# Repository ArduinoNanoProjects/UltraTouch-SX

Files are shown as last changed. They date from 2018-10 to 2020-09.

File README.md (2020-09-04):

 <pre>
 _   _  _  _                 _____                      _       _____ __   __
| | | || || |               |_   _|                    | |     /  ___|\ \ / /
| | | || || |_  _ __   __ _   | |    ___   _   _   ___ | |__   \ `--.  \ V /
| | | || || __|| '__| / _` |  | |   / _ \ | | | | / __|| '_ \   `--. \ /   \
| |_| || || |_ | |   | (_| |  | |  | (_) || |_| || (__ | | | | /\__/ // /^\ \
 \___/ |_| \__||_|    \__,_|  \_/   \___/  \__,_| \___||_| |_| \____/ \/   \/
 
Die Version der UltraTouch SX (Version 6) ist ausgestattet mit einem Nextion Display 
und sie versendet MIDI zur Nutzung der Räuspertasten. Sie kann vielseitig genutzt 
und erweitert werden ;)

Diese Idee entstand im Rahmen des Ultraschall-Projektes zum Themea: “MIDI Controller". 
Es gibt viele weitere Projekte von meinen Kollegen und der Podcast Community. 
Schau doch mal hier vorbei: https://ultraschall.fm

@developer   Michael McCouman Jr.
@version     UT[SX] V6
@date        04.Okt 2018 - 04.Seb 2020
@git:        https://github.com/McCouman
@website     https://wikibyte.org

Licence:     CC BY-NC-SA 4.0
Link:        https://creativecommons.org/licenses/by-nc-sa/4.0/deed.de
</pre>

# Overview

UltraTouch SX ist ein Midi-Controller für Podcaster. Sie kann als Räuspertaste aufgebaut und genutzt werden. Dies ist eine kleine Idee, wie ein Controller erarbeitet und gebaut werden kann:   

UltraTouch V6 - Overview

## Hard- und Software

### Arduino

Für dieses Projekt habe ich den <a href="https://store.arduino.cc/arduino-nano">Arduino Nano [0]</a> verwendet. Beachte, wenn Du größere Projekte aufbauen möchtest oder mehr Buttons benötigst, braucht dein Arduino mehr Speicher. Du benötigst daher, auf jedem Falle einen größeren Arduino für dein Projekt!

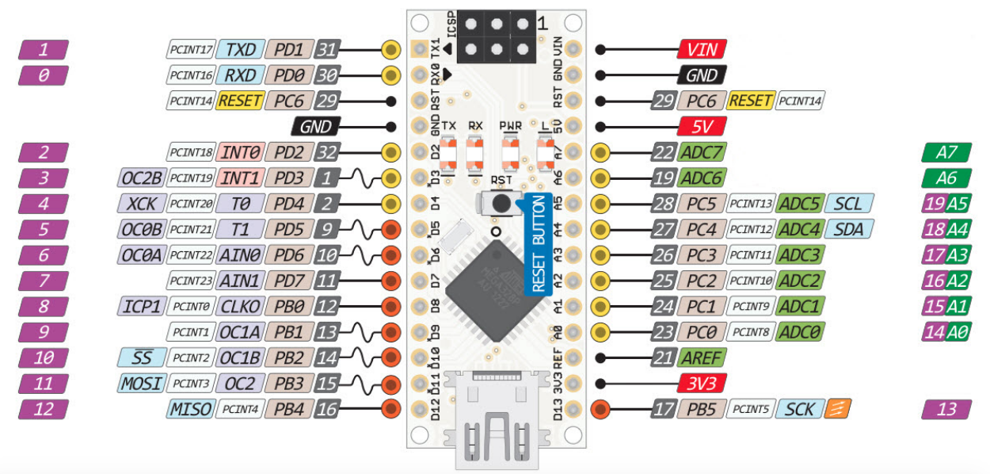
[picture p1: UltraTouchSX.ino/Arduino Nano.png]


### HC-SR04 Sensor

Das Ultraschall Modul HC-SR04 eignet sich zur Entfernungsmessung im Bereich zwischen 2cm und 2,5m mit einer Auflösung von 3mm. Es benötigt eine Versorgungsspannung von 5V bei einer Stromaufnahme von <2mA. Nach Triggerung misst das Modul
selbstständig die Entfernung und wandelt diese in ein PWM Signal welches am Ausgang zur Verfügung steht. Ein Messintervall hat dabei eine Dauer von 20ms. Es können daher 50 Messungen pro Sekunde durchgeführt werden. Es dient hier der schnellen und einfachen Lautstärkenanpassung über <i>Reaper Ultraschall</i>.

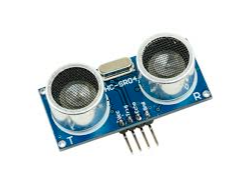
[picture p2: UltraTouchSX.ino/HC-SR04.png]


### WS-2812-B NeoPixel



Ein WS2812B wird auch kurz Neopixel genannt und es handelt sich hier um feste oder als Streifen vorhältige RGB LED. Ich habe für den beleuchteten Boden, 6 NeoPixel genutzt. Es können natürlich mehr oder weniger genutzt werden ;)

 

### Nextion Display

Das <a href="https://nextion.itead.cc">NextionDisplay [1]</a> ist eine einfache Möglichkeit sein eigenes Design und zusätzliche Software zu entwickeln. 

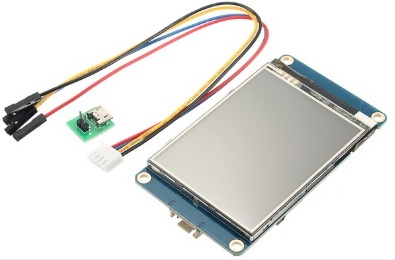
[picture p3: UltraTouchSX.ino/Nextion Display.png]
 

Die Software wird dabei direkt auf das Display geladen und kann über den Arduino angesprochen werden. Das in dieser Version genutzte Display ist das HMI TFT LCD Touch Display Module: <a href="https://www.itead.cc/nextion-nx4832t035.html">Nextion NX4832T035 - 3.5" [2]</a> (480 * 320). 

## Development

### LCARS Style (Design 2019)

Zur Entwicklung des Designs wurde <a href="https://www.adobe.com/de/products/photoshop.html">Photoshop <i>(R)(C)</i> [3]</a> benutzt. Das Design kann <a href="https://github.com/ArduinoNanoProjects/UltraTouch-SX/raw/master/NextionDisplay/UltraTouchSX-LCARS_2019/Data/PSD/UltraTouchSX-LCARS.psd">hier</a> geladen und verändert werden.

#### Load Screen
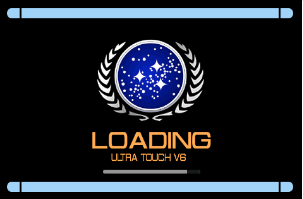
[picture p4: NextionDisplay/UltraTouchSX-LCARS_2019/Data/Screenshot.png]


##### Mute/Unmute Screen
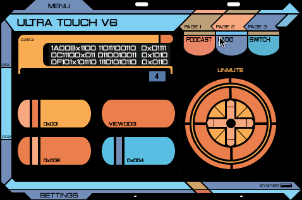
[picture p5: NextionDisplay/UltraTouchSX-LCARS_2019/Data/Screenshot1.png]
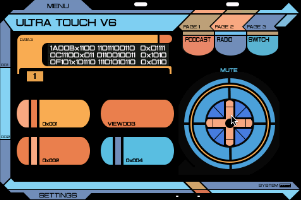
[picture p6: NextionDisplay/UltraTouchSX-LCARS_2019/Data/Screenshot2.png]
 

##### Settings Screen
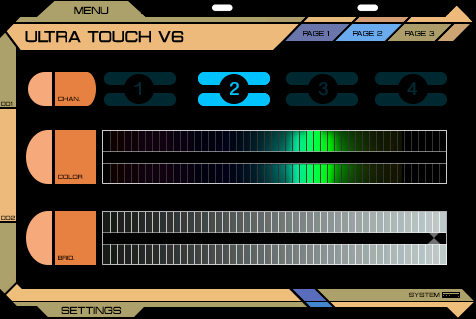
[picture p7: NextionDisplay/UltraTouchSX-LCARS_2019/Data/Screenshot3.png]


### U4 Style (Design 2020)

Zur Entwicklung des Designs wurde <a href="https://www.adobe.com/de/products/photoshop.html">Photoshop <i>(R)(C)</i> [3]</a> benutzt. Das Design 2020 kann <a href="https://github.com/ArduinoNanoProjects/UltraTouch-SX/raw/master/NextionDisplay/UltraTouchSX-U4_2020/Design-UltraTouch%20SX6%20US4/PSD/UltraTouchSX-U4.psd">hier</a> geladen und verändert werden.

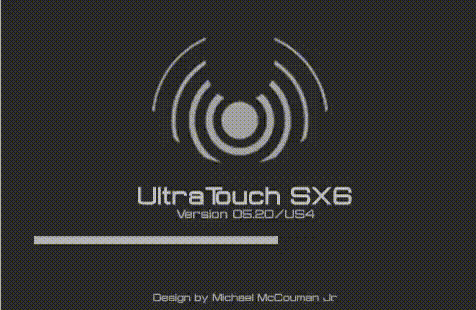
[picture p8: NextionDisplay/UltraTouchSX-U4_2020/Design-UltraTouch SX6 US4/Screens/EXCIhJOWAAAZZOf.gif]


https://twitter.com/i/status/1256654848210198529

Lade das "Betriebssystem" (<a href="https://github.com/ArduinoNanoProjects/UltraTouch-SX/raw/master/NextionDisplay/UltraTouchSX-U4_2020/UltraTouchSX6-US4.HMI">HMI</a>) auf das Nextion Display. Bearbeiten kannst Du es über das <a href="https://github.com/ArduinoNanoProjects/UltraTouch-SX/raw/master/NextionDisplay/UltraTouchSX-U4_2020/Design-UltraTouch%20SX6%20US4/UltraTouchSX6-US4.tft">UltraTouchSX6-US4.tft</a>.

#### Load Screen
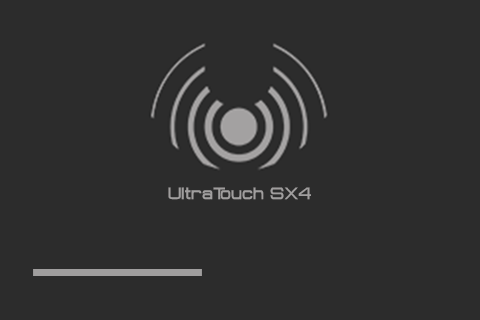
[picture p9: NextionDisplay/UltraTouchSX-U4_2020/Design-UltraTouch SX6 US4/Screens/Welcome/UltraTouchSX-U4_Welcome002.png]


##### Mute/Unmute Screen
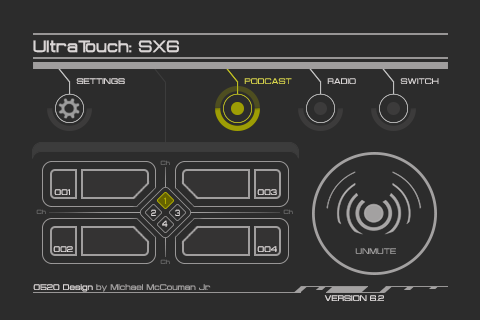
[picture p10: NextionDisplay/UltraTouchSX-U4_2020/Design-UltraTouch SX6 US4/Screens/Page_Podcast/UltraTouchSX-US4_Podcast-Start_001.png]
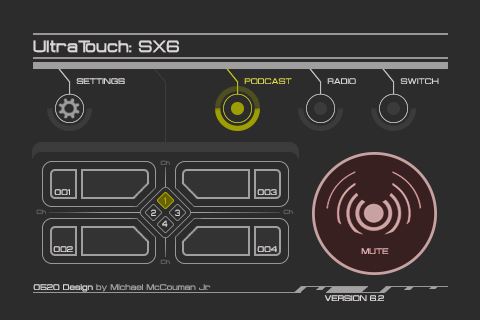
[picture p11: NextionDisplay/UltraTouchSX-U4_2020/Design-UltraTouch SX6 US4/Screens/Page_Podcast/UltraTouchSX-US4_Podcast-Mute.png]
 

##### Settings Screen
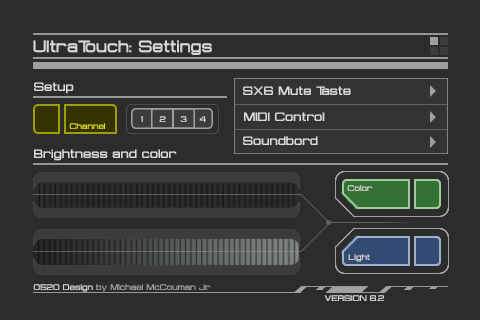
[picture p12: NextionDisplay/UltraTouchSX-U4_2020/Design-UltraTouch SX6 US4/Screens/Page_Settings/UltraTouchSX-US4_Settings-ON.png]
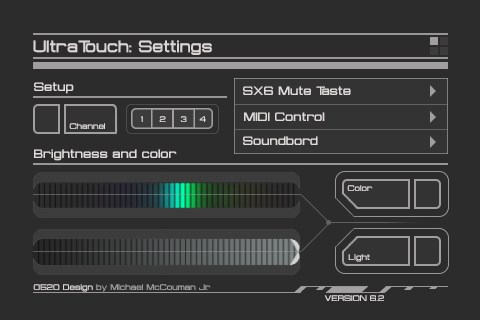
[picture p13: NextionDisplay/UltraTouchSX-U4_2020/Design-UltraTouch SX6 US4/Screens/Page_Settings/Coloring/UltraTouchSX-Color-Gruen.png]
 

#### 3D-Modell

<a href="https://github.com/ArduinoNanoProjects/UltraTouch-SX/tree/master/3D-Model">Hier</a> findest Du die 3d Modelle für das Gehäuse der UltraTouch SX für deinen 3D Printer. Ich habe hier den Desktop 3D-Drucker (Ender 2) genutzt, um das Gehäuse zu drucken. Der Druck besteht aus fünf einzelnen Modellen, die ich jedoch mit unterschiedlichen Materialien gedruckt habe:

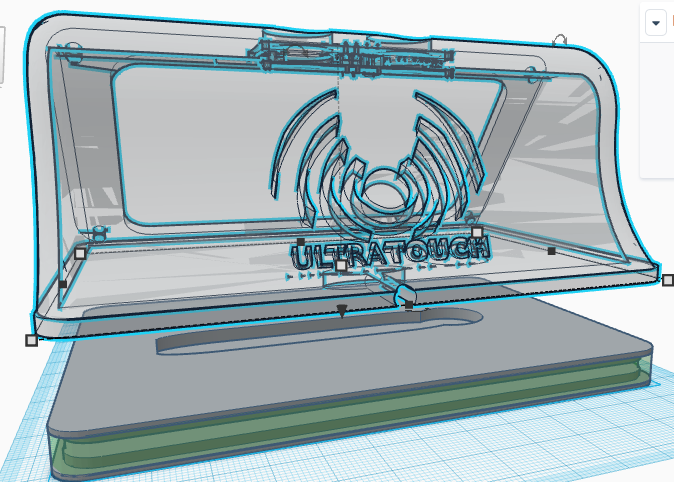
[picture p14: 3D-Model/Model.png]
UltraTouch Model für 3D Printer


- Body: ist das Gehäuse (schwarz: PLA)
- top_box: ist der Verbund für das Display (silber: PLA)
- Top: ist der obere Bereich der LED Box (silber: PETG)
- Bottom: ist der untere Bereich der LED Box (silber: PETG)
- Transparent: ist der Transparente Bereich der LED Box (transparent, dark glow: PLA)

*Achtung: Je nach Material gibt es unterschiedliche fließverhalten der Kunststoffe. Sie haben daher unterschiedlichen Schwund beim Drucken. Möchte man ein z.B. rein PLA-Material nutzen, so muss das Design angepasst werden oder nachträglich bearbeitet werden.*

### GUI Development

Des weiteren wird die IDE: Nextion Editor benötigt, um den Kernel der GUI als laufendes Systems zu entwickeln. Die Software ist leider nur für Windows erhältlich und kann direkt auf der Website von <a href="https://nextion.itead.cc/resources/download/">Nextion [4]</a> heruntergeladen werden. 

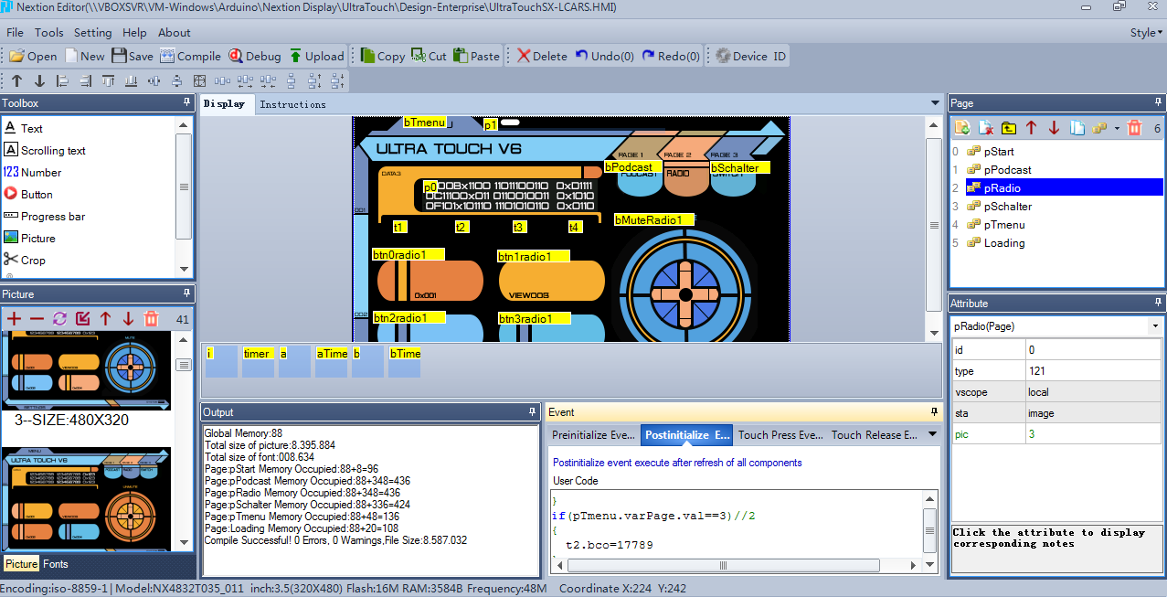
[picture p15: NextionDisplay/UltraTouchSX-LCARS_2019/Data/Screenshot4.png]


Zum laden des Projektes muss das "Betriebssystem", die <a href="https://github.com/ArduinoNanoProjects/UltraTouch-SX/raw/master/NextionDisplay/UltraTouchSX-LCARS_2019/UltraTouchSX-LCARS.HMI">UltraTouchSX-LCARS.HMI</a> oder <a href="https://github.com/ArduinoNanoProjects/UltraTouch-SX/raw/master/NextionDisplay/UltraTouchSX-U4_2020/UltraTouchSX6-US4.HMI">UltraTouchSX6-US4.HMI</a> mit dem <i>Nextion Exitor</i> geladen werden. Dabei wird des Betreibersystem auf das Display überspielt/geflashed.

### API Development

Hier findet sich der <a href="https://github.com/ArduinoNanoProjects/UltraTouch-SX/blob/master/UltraTouchSX.ino/UltraTouchSX/UltraTouchSX.ino">Beispiel Code</a> meiner UltraTouch SX in der Version 6.0 Variante. 

## Externe Links
- [0] Arduino Nano: https://store.arduino.cc/arduino-nano
- [1] Nextion Website: https://nextion.itead.cc
- [2] Nextion Display 3,5": https://www.itead.cc/nextion-nx4832t035.html
- [3] Photoshop: https://www.adobe.com/de/products/photoshop.html
- [4] Nextion Editor: https://nextion.itead.cc/resources/download/

## Lizenz
Diese Software steht unter CC BY-NC-SA 4.0 - Lizenz: Namensnennung - Nicht-kommerziell - Weitergabe unter gleichen Bedingungen 4.0 International (CC BY-NC-SA 4.0)

Dies ist eine allgemeinverständliche Zusammenfassung der Lizenz (die diese nicht ersetzt). Haftungsbeschränkung.

**Sie dürfen:**

* Teilen — das Material in jedwedem Format oder Medium vervielfältigen und weiterverbreiten
* Bearbeiten — das Material remixen, verändern und darauf aufbauen

Der Lizenzgeber kann diese Freiheiten nicht widerrufen solange Sie sich an die Lizenzbedingungen halten.

**Unter folgenden Bedingungen:**

* Namensnennung — Sie müssen angemessene Urheber- und Rechteangaben machen, einen Link zur Lizenz beifügen und angeben, ob Änderungen vorgenommen wurden. Diese Angaben dürfen in jeder angemessenen Art und Weise gemacht werden, allerdings nicht so, dass der Eindruck entsteht, der Lizenzgeber unterstütze gerade Sie oder Ihre Nutzung besonders.

* Nicht kommerziell — Sie dürfen das Material nicht für kommerzielle Zwecke nutzen.

* Weitergabe unter gleichen Bedingungen — Wenn Sie das Material remixen, verändern oder anderweitig direkt darauf aufbauen, dürfen Sie Ihre Beiträge nur unter derselben Lizenz wie das Original verbreiten.

* Keine weiteren Einschränkungen — Sie dürfen keine zusätzlichen Klauseln oder technische Verfahren einsetzen, die anderen rechtlich irgendetwas untersagen, was die Lizenz erlaubt.

**Hinweise:**

Sie müssen sich nicht an diese Lizenz halten hinsichtlich solcher Teile des Materials, die gemeinfrei sind, oder soweit Ihre Nutzungshandlungen durch Ausnahmen und Schranken des Urheberrechts gedeckt sind.

Es werden keine Garantien gegeben und auch keine Gewähr geleistet. Die Lizenz verschafft Ihnen möglicherweise nicht alle Erlaubnisse, die Sie für die jeweilige Nutzung brauchen. Es können beispielsweise andere Rechte wie Persönlichkeits- und Datenschutzrechte zu beachten sein, die Ihre Nutzung des Materials entsprechend beschränken.

Link: https://creativecommons.org/licenses/by-nc-sa/4.0/deed.de

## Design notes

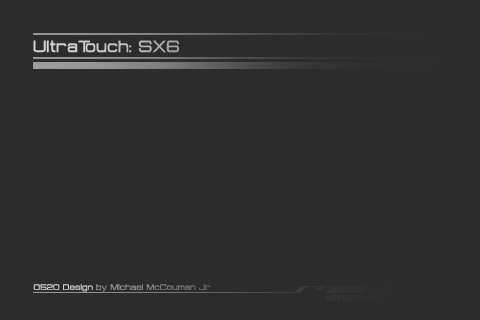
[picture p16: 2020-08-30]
NextionDisplay/UltraTouchSX-U4_2020/Design-UltraTouch SX6 US4/Screens/Loading-GIF_Home/UltraTouchSX-US4_LodingHome-002.png

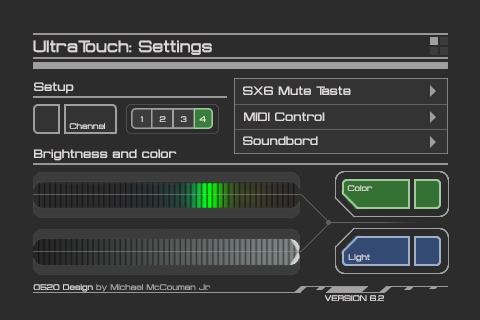
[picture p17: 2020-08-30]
NextionDisplay/UltraTouchSX-U4_2020/Design-UltraTouch SX6 US4/Screens/Page_Settings/Channel/UltraTouchSX-Channel4.png

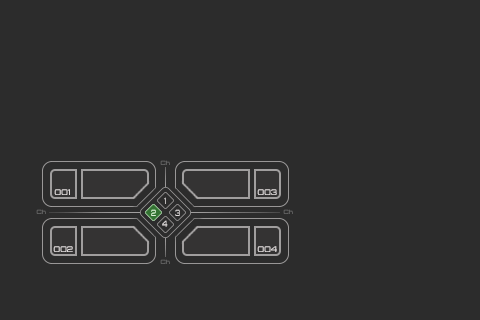
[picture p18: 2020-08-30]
NextionDisplay/UltraTouchSX-U4_2020/Design-UltraTouch SX6 US4/Screens/Views_Channel/UltraTouchSX-US4_Ch_2.png

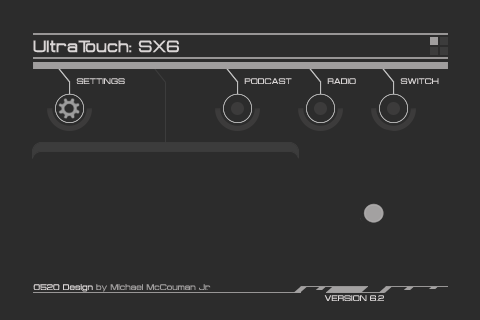
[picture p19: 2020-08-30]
NextionDisplay/UltraTouchSX-U4_2020/Design-UltraTouch SX6 US4/Screens/Loading-GIF_Home/UltraTouchSX-US4_LodingHome-009.png

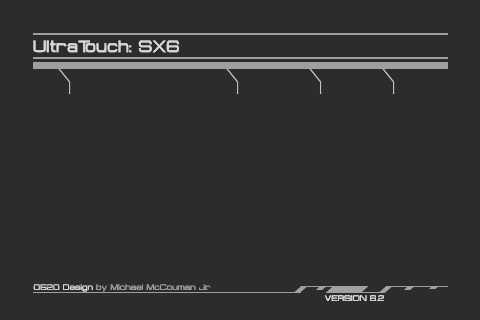
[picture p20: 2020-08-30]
NextionDisplay/UltraTouchSX-U4_2020/Design-UltraTouch SX6 US4/Screens/Loading-GIF_Home/UltraTouchSX-US4_LodingHome-005.png

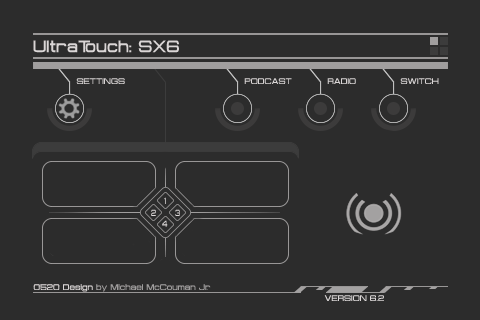
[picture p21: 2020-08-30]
NextionDisplay/UltraTouchSX-U4_2020/Design-UltraTouch SX6 US4/Screens/Loading-GIF_Home/UltraTouchSX-US4_LodingHome-011.png

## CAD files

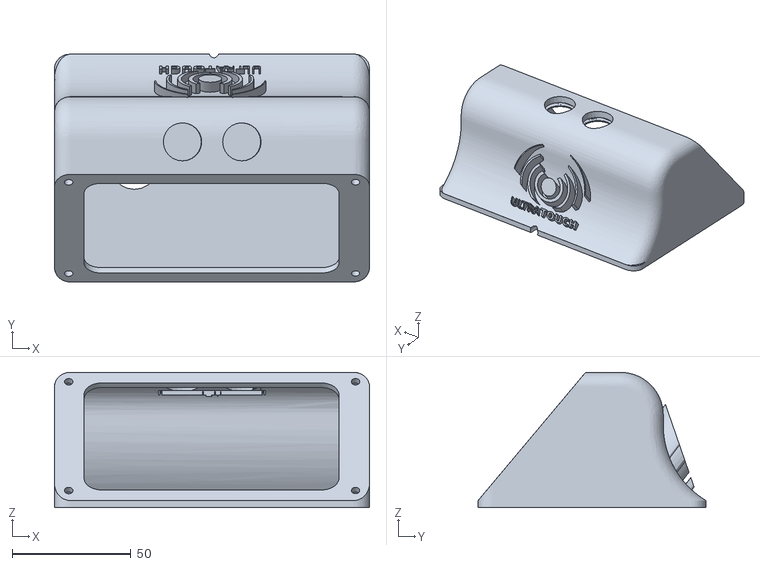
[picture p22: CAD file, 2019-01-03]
3D-Model/Body.stl
132.6 x 96.0 x 57.0

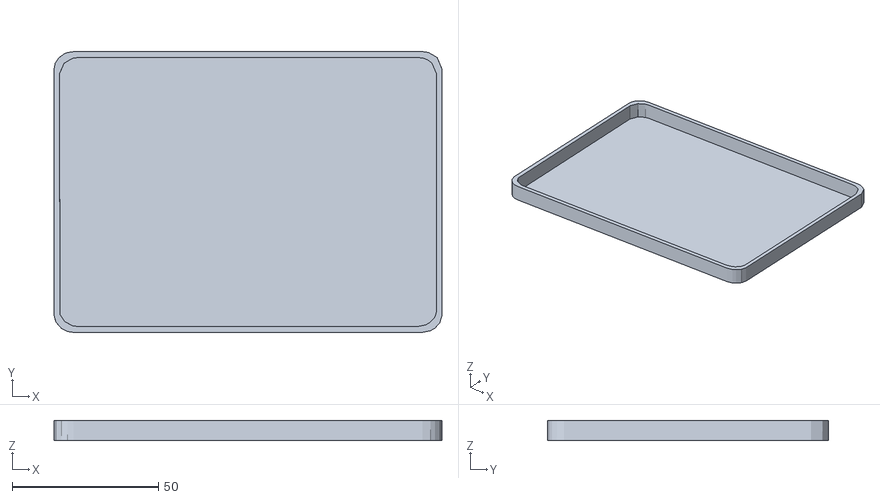
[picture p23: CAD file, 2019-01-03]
3D-Model/Transparent.stl
132.6 x 96.0 x 7.00

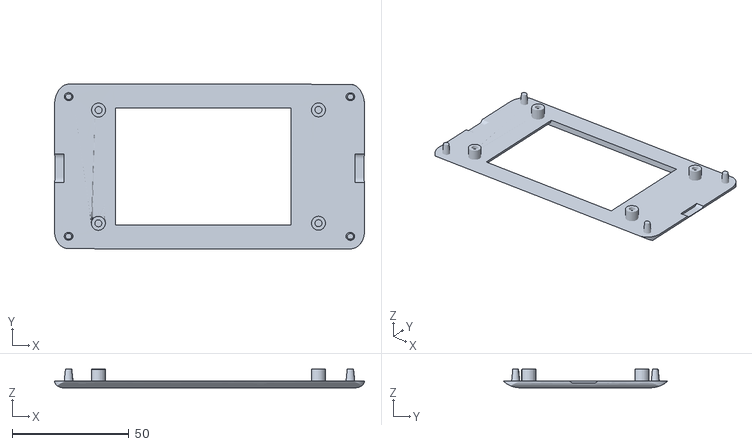
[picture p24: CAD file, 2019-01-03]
3D-Model/top_box.stl
132.7 x 70.5 x 8.02

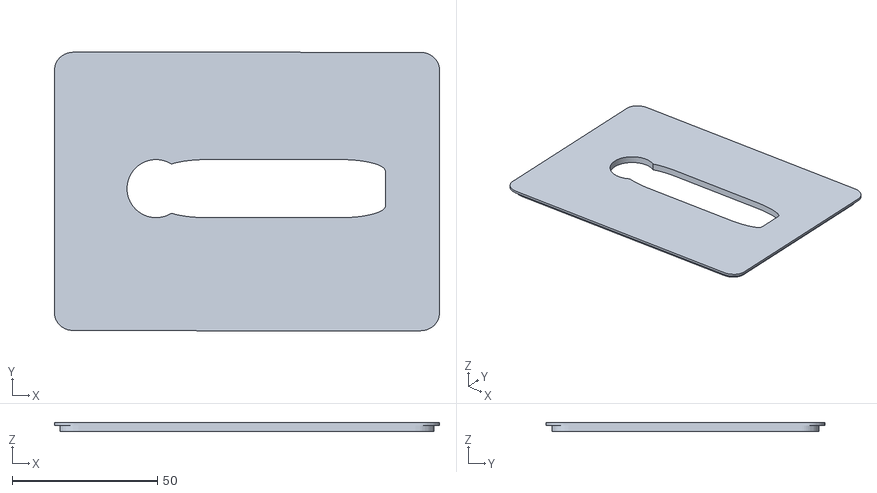
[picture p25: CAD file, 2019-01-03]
3D-Model/Top.stl
132.6 x 96.0 x 3.00

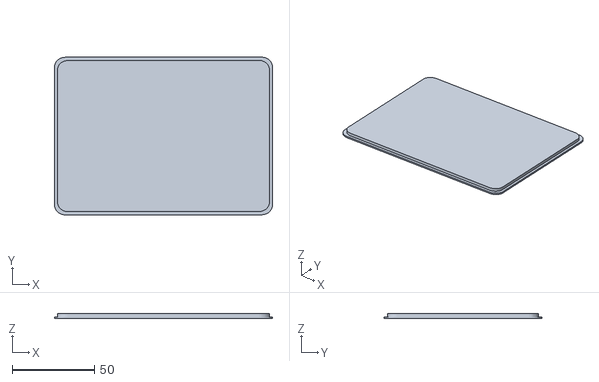
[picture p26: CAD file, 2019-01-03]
3D-Model/Bottom.stl
132.6 x 96.0 x 2.99

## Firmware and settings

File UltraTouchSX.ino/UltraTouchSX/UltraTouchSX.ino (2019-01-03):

/**
 *   _   _  _  _                 _____                      _       _____ __   __
 *  | | | || || |               |_   _|                    | |     /  ___|\ \ / /
 *  | | | || || |_  _ __   __ _   | |    ___   _   _   ___ | |__   \ `--.  \ V / 
 *  | | | || || __|| '__| / _` |  | |   / _ \ | | | | / __|| '_ \   `--. \ /   \ 
 *  | |_| || || |_ | |   | (_| |  | |  | (_) || |_| || (__ | | | | /\__/ // /^\ \
 *   \___/ |_| \__||_|    \__,_|  \_/   \___/  \__,_| \___||_| |_| \____/ \/   \/                                                                          
 *   
 * 
 * Die Version der UltraTouch SX (Version 6) ist ausgestattet mit einem Nextion-Display (R) 
 * und sie versendet MIDI zur Nutzung der Räuspertasten. Sie kann vielseitig genutzt, verändert 
 * und eingesetzt werden ;)
 * 
 * Diese Idee entstand im Rahmen des Ultraschall-Projektes zum Themea: "MIDI Controller". Es gibt 
 * viele weitere Projekte von mir und meinen Kollegen. 
 * Schaue doch mal vorbei: https://ultraschall.fm.
 * 
 * 
 * @developer   Michael McCouman Jr.
 * @version     UT[SX] V6
 * @date        04.Okt 2018 - 03. Jan 2019
 * @git:        https://github.com/McCouman
 * @website     https://wikibyte.org
 * 
 * Licence:     CC BY-NC-SA 4.0
 * Link:        https://creativecommons.org/licenses/by-nc-sa/4.0/deed.de
 *
**/

/*
 
   INFORMATIONEN ZUR LIZENZ:
   
   Diese Software steht unter CC BY-NC-SA 4.0 Lizenz: Namensnennung - Nicht-kommerziell - Weitergabe unter gleichen Bedingungen 
   4.0 International (CC BY-NC-SA 4.0). Dies ist eine allgemeinverständliche Zusammenfassung der Lizenz (die diese nicht ersetzt). 
   
   HAFTUNGSBESCHRÄNKUNG:
   
   Sie dürfen:
   - Teilen — das Material in jedwedem Format oder Medium vervielfältigen und weiterverbreiten
   - Bearbeiten — das Material remixen, verändern und darauf aufbauen
   - Der Lizenzgeber kann diese Freiheiten nicht widerrufen solange Sie sich an die Lizenzbedingungen halten.
   
   Unter folgenden Bedingungen:
   - Namensnennung — Sie müssen angemessene Urheber- und Rechteangaben machen, einen Link zur Lizenz beifügen und angeben, 
     ob Änderungen vorgenommen wurden. Diese Angaben dürfen in jeder angemessenen Art und Weise gemacht werden, allerdings 
     nicht so, dass der Eindruck entsteht, der Lizenzgeber unterstütze gerade Sie oder Ihre Nutzung besonders.
   
   - Nicht kommerziell — Sie dürfen das Material nicht für kommerzielle Zwecke nutzen.
   
   - Weitergabe unter gleichen Bedingungen — Wenn Sie das Material remixen, verändern oder anderweitig direkt darauf aufbauen, 
     dürfen Sie Ihre Beiträge nur unter derselben Lizenz wie das Original verbreiten.
   
   - Keine weiteren Einschränkungen — Sie dürfen keine zusätzlichen Klauseln oder technische Verfahren einsetzen, 
     die anderen rechtlich irgendetwas untersagen, was die Lizenz erlaubt.
   
   
   Hinweise:
   Sie müssen sich nicht an diese Lizenz halten hinsichtlich solcher Teile des Materials, die gemeinfrei sind, 
   oder soweit Ihre Nutzungshandlungen durch Ausnahmen und Schranken des Urheberrechts gedeckt sind. Es werden keine Garantien 
   gegeben und auch keine Gewähr geleistet. Die Lizenz verschafft Ihnen möglicherweise nicht alle Erlaubnisse, die Sie für die 
   jeweilige Nutzung brauchen. Es können beispielsweise andere Rechte wie Persönlichkeits- und Datenschutzrechte zu beachten sein, 
   die Ihre Nutzung des Materials entsprechend beschränken.
   
   Link:
   - https://creativecommons.org/licenses/by-nc-sa/4.0/deed.de

 * 
*/

// BIBLIOTHEK:
#include "Nextion.h"

#include <Adafruit_NeoPixel.h>
#ifdef __AVR__
  #include <avr/power.h>
#endif

// LED PIN:
#define LED         13   // OnBoard LED des Arduino Nanos
#define PIN         12   // Signal Pin für NeoPixel
#define NUMPIXELS    6   // Anzahl der NeoPixel

// VARS:
int Toggle      = HIGH;  // Speichert den Wert des Button Peak View
int Switch      = HIGH;  // Speichert den Wert des MIDI-Schalters 
int Bridhness   = 255;   // Speichert den Wert der Helligkeit für die Bodenbeleuchtung
int Modus       = 1;     // Speichert den Wert ob Mute oder Unmute für die Farben eines Callbacks
int Channel     = 1;     // Speichert die Werte für die Kanäle 1 bis 4 für die Mute/Unmute Taste
int Colors      = 1;     // Speichert die Werte für die Farben 1 bis 9 für die Bodenbeleuctung
int Light       = 1;     // Speichert die Werte für die Helligkeit 1 bis 8 für die Bodenbeleuctung

// VARS HCSR04
int triggerPin  = 2;
int echoPin     = 3;

// NEOPIXEL:
Adafruit_NeoPixel pixels = Adafruit_NeoPixel(NUMPIXELS, PIN, NEO_GRB + NEO_KHZ800);


/**
 * Deklaration der Obejekte für das Nextion-Display:
 * Bsp.: (page id = 0, component id = 1, component name = "b0")
*/
// PAGES:
//pPodcast1 (ID:1)
NexButton btn0pod = NexButton(1, 3, "btn0pod");                 // Button top/left
NexButton btn1pod = NexButton(1, 4, "btn1pod");                 // Button top/right
NexButton btn2pod = NexButton(1, 5, "btn2pod");                 // Button down/left
NexButton btn3pod = NexButton(1, 6, "btn3pod");                 // Button down/right
NexButton btnMutePod = NexButton(1, 8, "btnMutePod");           // Mute Button
//pRadio1 (ID:2)
NexButton btn0radio = NexButton(2, 3, "btn0radio");             // Button top/left
NexButton btn1radio = NexButton(2, 4, "btn1radio");             // Button top/right
NexButton btn2radio = NexButton(2, 5, "btn2radio");             // Button down/left
NexButton btn3radio = NexButton(2, 6, "btn3radio");             // Button down/right
NexButton btnMuteRadio = NexButton(2, 8, "btnMuteRadio");       // Unmute Button
//pSchalter1 (ID:3)
NexButton btn0switch = NexButton(3, 3, "btn0switch");           // Button top/left
NexButton btn1switch = NexButton(3, 4, "btn1switch");           // Button top/right
NexButton btn2switch = NexButton(3, 5, "btn2switch");           // Button down/left
NexButton btn3switch = NexButton(3, 6, "btn3switch");           // Button down/right
NexDSButton btnMuteSwitch = NexDSButton(3, 8, "btnMuteSwitch"); // Mute/Unmute Switch

// MENU:
//pTmenu (ID:4)
NexButton bGoPage = NexButton(4, 1, "bGoPage");                // Button Channel (1 bis 4)
NexButton bGoColor = NexButton(4, 6, "bGoColor");              // Button Color 
NexButton bGoLight = NexButton(4, 7, "bGoLight");              // Button Helligkeit

// PAGES OVERVIEW:
NexPage pStart      = NexPage(0, 0, "Start");
NexPage pPodcast    = NexPage(1, 0, "pPodcast");
NexPage pRadio      = NexPage(2, 0, "pRadio");
NexPage pSchalter   = NexPage(3, 0, "pSchalter");
NexPage pTmenu      = NexPage(4, 0, "pTmenu");




/**
 * Registrieren aller Objekte für die TouchEvent Liste:
*/
char buffer[100] = {0};

NexTouch *nex_listen_list[] = {
  // Pages:
  &btnMutePod,
  &btn0pod,
  &btn1pod,
  &btn2pod,
  &btn3pod,
  &btnMuteRadio,
  &btn0radio,
  &btn1radio,
  &btn2radio,
  &btn3radio,
  &btnMuteSwitch,
  &btn0switch,
  &btn1switch,
  &btn2switch,
  &btn3switch,
  // Menu
  &bGoPage,
  &bGoColor,
  &bGoLight,
  NULL
};


/**
 * MENU CALLBACKS:
 */
// MENU: CHANNEL
void bGoChannelPushCallback(void *ptr) {
  Channel = Channel +1 ;
  if (Channel == 5) {
    Channel = 1;
  }
}

// MENU: COLOR
void bGoColorPushCallback(void *ptr) {
  Colors = Colors +1 ;
  NeoBottomSwitch(Colors);
}

// MENU: BRIDHNESS
void bGoLightPushCallback(void *ptr) {
  Light = Light +1 ;
  if (Light == 1) {
    Bridhness = 255;
    NeoBottomSwitch(Colors);
  }
  if (Light == 2) {
    Bridhness = 0;
    NeoBottomSwitch(Colors);
  }
  if (Light == 3) {
    Bridhness = 25;
    NeoBottomSwitch(Colors);
  }
  if (Light == 4) {
    Bridhness = 60;
    NeoBottomSwitch(Colors);
  }
  if (Light == 5) {
    Bridhness = 110;
    NeoBottomSwitch(Colors);
  }
  if (Light == 6) {
    Bridhness = 160;
    NeoBottomSwitch(Colors);
  }
  if (Light == 7) {
    Bridhness = 200;
    NeoBottomSwitch(Colors);
  }
  if (Light == 8) {
    Bridhness = 230;
    NeoBottomSwitch(Colors);
  }
  if (Light == 9) {
    Bridhness = 255;
    NeoBottomSwitch(Colors);
    Light = 1;
  }
}


/**
 * PODCAST: MUTE/UNMUTE
*/
// PAGE 1: CALLBACKS PODCAST
void bMutePodcastPushCallback(void *ptr) {
  Speak("OFF", Channel);
  
  //== rot? 
  if (Colors == 5) {
    NeoTop(0, Bridhness, 0);
  } else {
    NeoBottom(Bridhness, 0, 0); //rot 
  }

  Modus = 1;
}
void bMutePodcastPopCallback(void *ptr) {
  Speak("ON", Channel);
  NeoBottomSwitch(Colors);
  Modus = 1;
}


/**
 * RADIO: UNMUTE/MUTE
*/
// PAGE 1: CALLBACKS RADIO
void bMuteRadioPushCallback(void *ptr) {
  Speak("ON", Channel);
  NeoBottomSwitch(Colors);
  
  Modus = 0;
}
void bMuteRadioPopCallback(void *ptr) {
  Speak("OFF", Channel);

  //== rot? 
  if (Colors == 5) {
    NeoTop(0, Bridhness, 0);
  } else {
    NeoBottom(Bridhness, 0, 0); //rot 
  }
  Modus = 0;
}


/**
 * SCHALTER: SWITCH MUTE/UNMUTE
*/
// PAGE 1: CALLBACKS SWITCH
void bMuteSwitchPopCallback(void *ptr) {
  Switch = !Switch;
  if (Switch == HIGH) {
    NeoBottomSwitch(Colors);
    Speak("ON", Channel);
    Modus = 1;
  }
  if (Switch == LOW) {
    //== rot? 
    if (Colors == 5) {
      NeoTop(0, Bridhness, 0);
    } else {
      NeoBottom(Bridhness, 0, 0); //rot 
    }
    
    Speak("OFF", Channel);
    Modus = 0;
  }
}


/*
 * BUTTONS: 4er Buttons
*/
// PAGE 1 - 4: BUTTON TOP LEFT
void btn0PushCallback(void *ptr) {
  if(Modus == 1){
    NeoTop(Bridhness, 0, 0);  
  }
  if(Modus == 0){
    NeoBottomSwitch(Colors);
  }
  digitalWrite(LED, HIGH);
  delay(500);
  Note(1);
  digitalWrite(LED, LOW);
  delay(500);
  if(Modus == 1){
    NeoBottomSwitch(Colors);
  }
  if(Modus == 0){
    NeoTop(Bridhness, 0, 0);
  }
}

// PAGE 1 - 4: BUTTON TOP RIGHT
void btn1PushCallback(void *ptr) {
  Toggle = !Toggle;
  if(Modus == 1){
    NeoTop(Bridhness, 0, 0);  
  }
  if(Modus == 0){
    NeoBottomSwitch(Colors);
  }
  //-MIDI AUSGABE
  digitalWrite(LED, HIGH);
  delay(500);
  if(Toggle == LOW){
    Note(4);
  } else {
    Note(5);
  }
  digitalWrite(LED, LOW);
  delay(500);
  if(Modus == 1){
    NeoBottomSwitch(Colors);
  }
  if(Modus == 0){
    NeoTop(Bridhness, 0, 0);
  }
}

// PAGE 1 - 4: BUTTON DOWN LEFT
void btn2PushCallback(void *ptr) {
  if(Modus == 1){
    NeoTop(Bridhness, 0, 0);  
  }
  if(Modus == 0){
    NeoBottomSwitch(Colors);
  }
  //-MIDI AUSGABE
  digitalWrite(LED, HIGH);
  delay(500);
  Note(2);
  digitalWrite(LED, LOW);
  delay(500);
  if(Modus == 1){
    NeoBottomSwitch(Colors);
  }
  if(Modus == 0){
    NeoTop(Bridhness, 0, 0);
  }
}

// PAGE 1 - 4: BUTTON DOWN RIGHT
void btn3PushCallback(void *ptr) {
  if(Modus == 1){
    NeoTop(Bridhness, 0, 0);  
  }
  if(Modus == 0){
    NeoBottomSwitch(Colors);
  }
  //-MIDI AUSGABE
  digitalWrite(LED, HIGH);
  delay(500);
  Note(3);
  digitalWrite(LED, LOW);
  delay(500);
  if(Modus == 1){
    NeoBottomSwitch(Colors);
  }
  if(Modus == 0){
    NeoTop(Bridhness, 0, 0);
  }
}


/**
 * SETUP PROGRAM
 */
void setup(void) {
  /* Starte Serielle Kommunikation mit 9600 Baut */
  Serial.begin(9600);

  /* Initialisieren der NeoPixel Lib */
  #if defined (__AVR_ATtiny85__)
    if (F_CPU == 16000000) clock_prescale_set(clock_div_1);
  #endif
  pixels.begin();
  
  /* Initialisieren der Lib: ITEADLIB_Arduino_Nextion */
  nexInit();

  /* Angaben aller Pop- und Push-Events als Callback */
  //Events Podcast
  btnMutePod.attachPush(bMutePodcastPushCallback, &btnMutePod);     // Mute Button 
  btnMutePod.attachPop(bMutePodcastPopCallback, &btnMutePod);       // Unmute Button 
  btn0pod.attachPush(btn0PushCallback, &btn0pod);
  btn1pod.attachPush(btn1PushCallback, &btn1pod);
  btn2pod.attachPush(btn2PushCallback, &btn2pod);
  btn3pod.attachPush(btn3PushCallback, &btn3pod);
  
  //Events Radio
  btnMuteRadio.attachPush(bMuteRadioPushCallback, &btnMuteRadio);   // Unmute Button 
  btnMuteRadio.attachPop(bMuteRadioPopCallback, &btnMuteRadio);     // Mute Button 
  btn0radio.attachPush(btn0PushCallback, &btn0radio);
  btn1radio.attachPush(btn1PushCallback, &btn1radio);
  btn2radio.attachPush(btn2PushCallback, &btn2radio);
  btn3radio.attachPush(btn3PushCallback, &btn3radio);
  
  //Events Schalter
  btnMuteSwitch.attachPop(bMuteSwitchPopCallback, &btnMuteSwitch);  // Mute || Unmute Switch
  btn0switch.attachPush(btn0PushCallback, &btn0switch);
  btn1switch.attachPush(btn1PushCallback, &btn1switch);
  btn2switch.attachPush(btn2PushCallback, &btn2switch);
  btn3switch.attachPush(btn3PushCallback, &btn3switch);
  
  //Event Channel
  bGoPage.attachPush(bGoChannelPushCallback, &bGoPage);
  //Event Color
  bGoColor.attachPush(bGoColorPushCallback, &bGoColor);
  //Event Brightness
  bGoLight.attachPush(bGoLightPushCallback, &bGoLight);

  /* Setze LED auf Ausgabe */
  pinMode(LED, OUTPUT);

  /* Setze Ultrachall Sensor (HC-SR04) */
  pinMode(triggerPin, OUTPUT);
  pinMode(echoPin, INPUT);

  /* Starte Regenbogen für NeoPixel Test */
  rainbowCycle(1000);
  delay(1000);

  /* Setze NeoPixel auf Grün */
  NeoTop(0, 255, 0);
  NeoBottom(0, 255, 0);
}


/**
 * PROGRAM LOOP
 */
void loop(void) {
  /* Nutzen der Events */
  nexLoop(nex_listen_list);

  /* Lese den Ultraschall-Sensor aus */
  //HCSR04_Read();
  sensorAbfragen(triggerPin, echoPin, 1);
}

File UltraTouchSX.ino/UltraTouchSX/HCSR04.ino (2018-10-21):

/**
 * Abfragewerte in 10er Schritten (einfach) für HCSR04 Sensor
 * 
 * Es werden hier statische Werte von 0-127 als CC versendet.
 * Hier kann z.B.: der Masterregler angesprochen werden.
 */
void sensorAbfragen(byte triggerPin, byte echoPin, byte ctrlNummer) {
  digitalWrite(triggerPin, LOW);
  delayMicroseconds(3);
  digitalWrite(triggerPin, HIGH);
  delayMicroseconds(10);
  digitalWrite(triggerPin, LOW);

  long sensorWert = pulseIn(echoPin, HIGH);

  if ( (sensorWert <= 2001) && (sensorWert >= 239)) {
    byte sensorMIDI = map(sensorWert, 240, 2000, 0, 127);

    if ( (sensorMIDI <= 6) && (sensorMIDI >= 0)) {
      sendeMIDI(191, 5, 0);
      /*Serial.print(sensorWert);
      Serial.print("  |0-4|  0");
      Serial.println();*/
    }
    if ( (sensorMIDI <= 11) && (sensorMIDI >= 6)) {
      sendeMIDI(191, 5, 10);
      /*Serial.print(sensorWert);
      Serial.print("  |5-11|  10");
      Serial.println();*/
    }
    if ( (sensorMIDI <= 21) && (sensorMIDI >= 11)) {
      sendeMIDI(191, 5, 20);
      /*Serial.print(sensorWert);
      Serial.print("  |11-21|  20");
      Serial.println();*/
    }
    if ( (sensorMIDI <= 31) && (sensorMIDI >= 21)) {
      sendeMIDI(191, 5, 30);
      /*Serial.print(sensorWert);
      Serial.print("  |21-30|  30");
      Serial.println();*/
    }
    if ( (sensorMIDI <= 41) && (sensorMIDI >= 31)) {
      sendeMIDI(191, 5, 40);
      /*Serial.print(sensorWert);
      Serial.print("  |31-41|  40");
      Serial.println();*/
    }
    if ( (sensorMIDI <= 51) && (sensorMIDI >= 41)) {
      sendeMIDI(191, 5, 50);
      /*Serial.print(sensorWert);
      Serial.print("  |41-51|  50");
      Serial.println();*/
    }
    if ( (sensorMIDI <= 61) && (sensorMIDI >= 51)) {
      sendeMIDI(191, 5, 60);
      /*Serial.print(sensorWert);
      Serial.print("  |51-61|  60");
      Serial.println();*/
    }
    if ( (sensorMIDI <= 71) && (sensorMIDI >= 61)) {
      sendeMIDI(191, 5, 70);
      /*Serial.print(sensorWert);
      Serial.print("  |61-71|  70");
      Serial.println();*/
    }
    if ( (sensorMIDI <= 81) && (sensorMIDI >= 71)) {
      sendeMIDI(191, 5, 80);
      /*Serial.print(sensorWert);
      Serial.print("  |71-81|  80");
      Serial.println();*/
    }
    if ( (sensorMIDI <= 91) && (sensorMIDI >= 81)) {
      sendeMIDI(191, 5, 90);
      /*Serial.print(sensorWert);
      Serial.print("  |81-91|  90");
      Serial.println();*/
    }
    if ( (sensorMIDI <= 101) && (sensorMIDI >= 91)) {
      sendeMIDI(191, 5, 100);
      /*Serial.print(sensorWert);
      Serial.print("  |91-101|  100");
      Serial.println();*/
    }
    if ( (sensorMIDI <= 115) && (sensorMIDI >= 101)) {
      sendeMIDI(191, 5, 110);
      /*Serial.print(sensorWert);
      Serial.print("  |101-115|  110");
      Serial.println();*/
    }
    if ( (sensorMIDI <= 128) && (sensorMIDI >= 115)) {
      sendeMIDI(191, 5, 127);
      /*Serial.print(sensorWert);
      Serial.print("  |115-128|  127");
      Serial.println();*/
    }
    //sendeMIDI(191, 5, sensorMIDI);
  }
}

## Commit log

2018-10-04 fixed switch
    Update V2.0
2018-10-04 fixed switch
2018-10-05 Erweiterungen mit 4 Mute Buttons
    * Erweiterungen im Menü zum hinspringen der Mute Pages 1 bis 4
    * Zusammenfassung des Menüs
    * Erst einmal Loadpage abgeschaltet
2018-10-05 Erweiterungen mit 4 Mute Buttons
    * Angaben als Erweiterungen sind auskommentiert.
    * Diese können nicht mit einem Arduino Nano betreiben werden, da der Speicher zu klein dafür ist.
2018-10-05 fixed numbers
    falsche callbacks überschrieben
    [UltraTouchSX.ino]
2018-10-05 fixed and tested 1-4 Buttons
    * fehlende Seiten-Nr.
    * live test -OK
    * entfernen der defines
    [UltraTouchSX.ino]
2018-10-05 NeoPixel (5x) für mehr Licht
    * NeoPixel (Anschluss 3V) für Bodenbeleuchtung und Signalgebung
2018-10-05 NeoPixel Functions
    Bessere Dokumentation der NeoPixel Funktionen
2018-10-05 fixed nextInit()
    - Dokumentation verbessert
    - fix nach dem Test der NexoPixel com
    [UltraTouchSX.ino]
2018-10-21 HCSR04
    - Neu: Ultraschallsensor (HCSR04)
    - Verbesserungen mit neuer Struktur und Layout
    - LCARS Style für NextDisplay
2019-01-03 Release V2.1 (UTv6.0 - 2019)
    - fixed hdi
    - new menu and style
    - design fixing
    - position fix
    - update ino
    [Body.stl, Bottom.stl, Top.stl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]
